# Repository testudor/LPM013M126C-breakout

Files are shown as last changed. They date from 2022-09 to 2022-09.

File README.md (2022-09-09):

# LPM013M126C breakout



This is a breakout board for the LPM013M126C MIP display from JDI. It makes it easy to use with various dev boards like Arduino, etc.

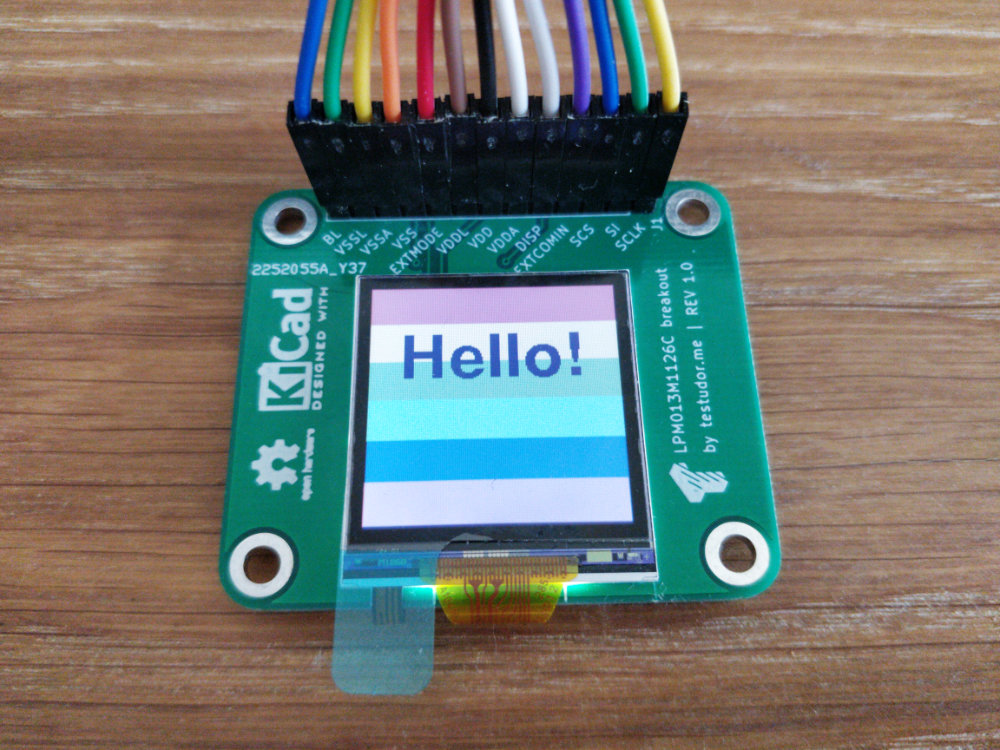
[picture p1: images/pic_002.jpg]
LPM013M126C breakout photo


## Wiring

> **Note** Logic levels as well as supply voltages are 3.3 V. If your use case requires 5 V you'll have to use a level shifter and change the current limiting resistors for the backlight LEDs.

> **Note** Yes, this board has many pins. The display offers the possibility to use separate analog/logic power supplies and I decided to keep this functionality. Same goes for the backlight. For most use cases it's possible to use a common supply for everything.

| PIN | Description | Connect to |
| --- | --- | --- |
| SCLK | Serial Clock Signal | Connect to MCU SPI Clock |
| SI | Serial Data Input Signal | Connect to MCU SPI MOSI |
| SCS | Chip Select Signal | Connect to MCU SPI Chip Select |
| EXTCOMIN | COM Inversion Polarity Input | Not connected |
| DISP | Display ON/OFF Switching Signal | Connect to any digital pin |
| VDDA | Power Supply for Analog | Connect to +3.3 V |
| VDD | Power Supply for Logic | Connect to +3.3 V |
| VDDL | Power Supply for LED | Connect to +3.3 V |
| EXTMODE  | COM Inversion Mode Select Terminal | Not connected |
| VSS | Logic Ground | Connect to GND |
| VSSA | Analog Ground | Connect to GND |
| VSSL | LED Ground | Connect to GND |
| BL | LED Backlight Input | Connect to any digital pin |

## EXTMODE Jumper

Set EXTMODE to 'L' for use with the library mentioned below

## Software

The display works great with the [JDI_MIP_Display](https://github.com/Gbertaz/JDI_MIP_Display) library! Just make sure to set the right resolution in the config file.

## Further Information

For more information regarding the display please refer to the [official datasheet](https://www.j-display.com/product/pdf/Datasheet/5LPM013M126C_specification_ver03.pdf)!

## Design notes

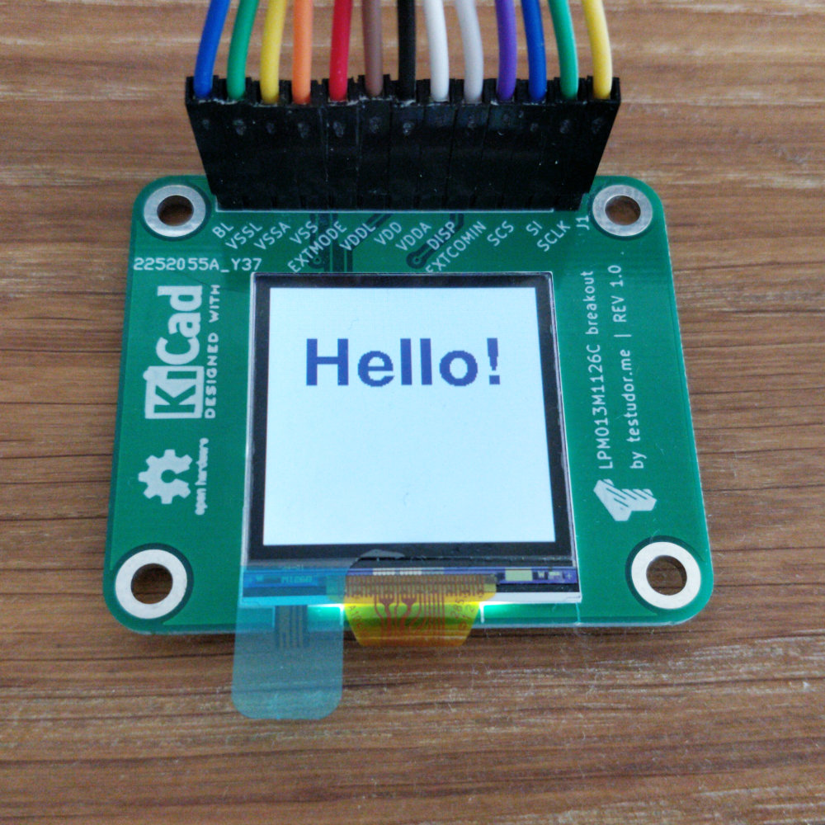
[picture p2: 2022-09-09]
images/pic_001.jpg

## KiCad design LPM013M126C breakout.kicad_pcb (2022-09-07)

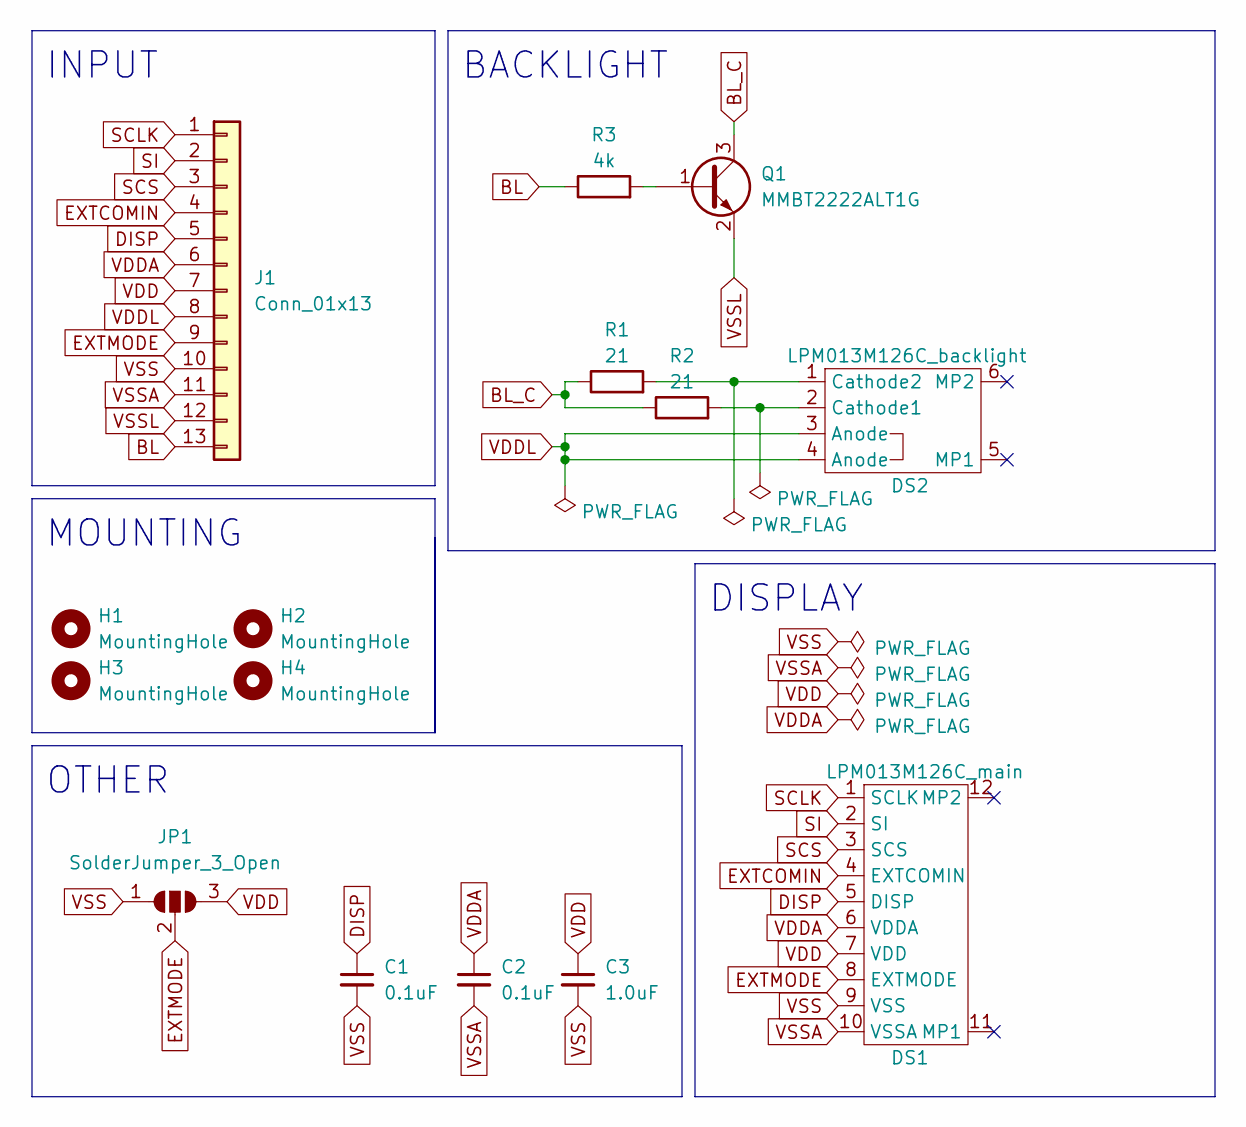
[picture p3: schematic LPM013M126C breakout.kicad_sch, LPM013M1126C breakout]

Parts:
C1, C2: 0.1uF; C_0402_1005Metric
C3: 1.0uF; C_0402_1005Metric
DS1: LPM013M126C_main; 5034801000
DS2: LPM013M126C_backlight; 503480-0400
H1, H2, H3, H4: MountingHole; MountingHole_3.2mm_M3_ISO14580_Pad_TopBottom
J1: Conn_01x13; PinHeader_1x13_P2.54mm_Vertical
JP1: SolderJumper_3_Open; SolderJumper-3_P1.3mm_Open_RoundedPad1.0x1.5mm_NumberLabels
Q1: MMBT2222ALT1G; SOT-23
R1, R2: 21; R_0402_1005Metric
R3: 4k; R_0402_1005Metric

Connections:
BL: J1.13, R3.1
BL_C: Q1.3 (C), R1.1, R2.1
DISP: C1.1, DS1.5 (DISP), J1.5
EXTCOMIN: DS1.4 (EXTCOMIN), J1.4
EXTMODE: DS1.8 (EXTMODE), J1.9, JP1.2 (C)
unnamed: DS2.1 (Cathode2), R1.2
unnamed: DS2.2 (Cathode1), R2.2
unnamed: Q1.1 (B), R3.2
SCLK: DS1.1 (SCLK), J1.1
SCS: DS1.3 (SCS), J1.3
SI: DS1.2 (SI), J1.2
VDD: C3.1, DS1.7 (VDD), J1.7, JP1.3 (B)
VDDA: C2.1, DS1.6 (VDDA), J1.6
VDDL: DS2.3 (Anode), DS2.4 (Anode), J1.8
VSS: C1.2, C3.2, DS1.9 (VSS), J1.10, JP1.1 (A)
VSSA: C2.2, DS1.10 (VSSA), J1.11
VSSL: J1.12, Q1.2 (E)

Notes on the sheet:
DISPLAY
MOUNTING
OTHER
INPUT
BACKLIGHT

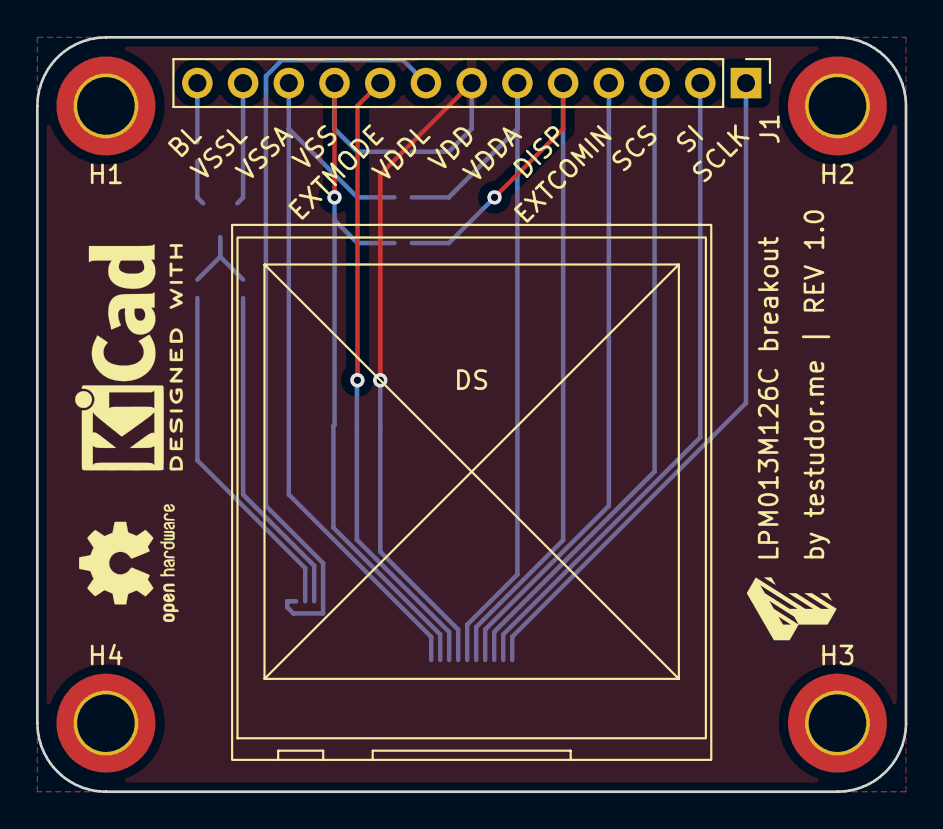
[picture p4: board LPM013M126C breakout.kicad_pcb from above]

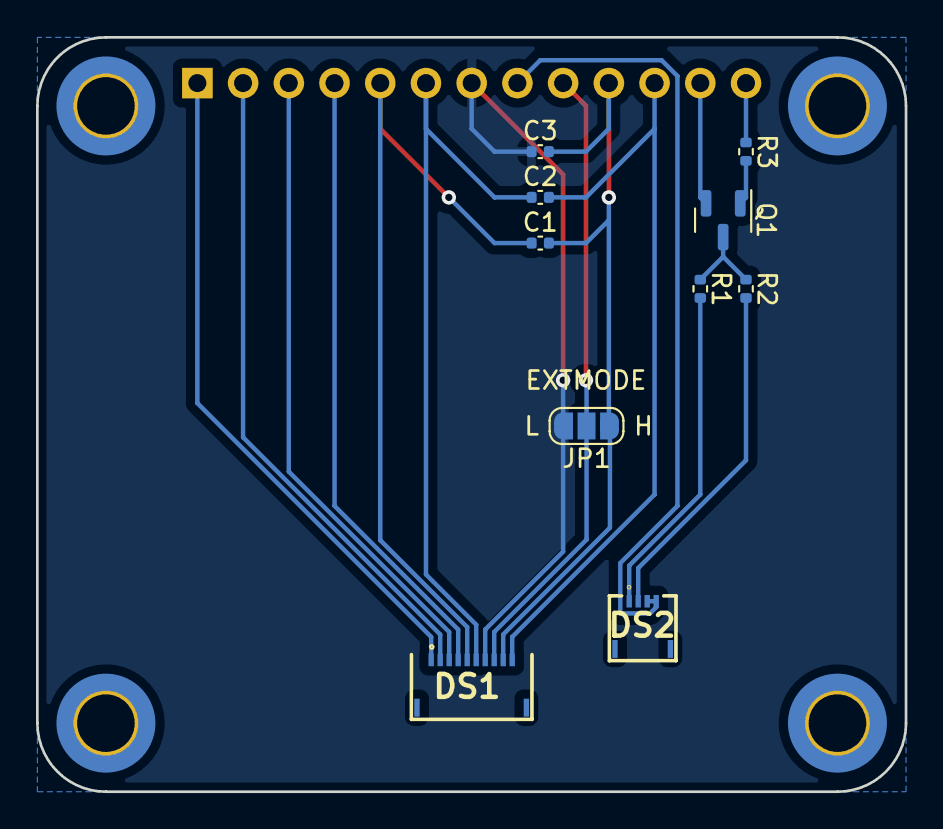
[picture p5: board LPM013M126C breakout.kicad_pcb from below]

Board: 2 copper layers, 48.3 x 41.9 mm, 19 parts (10 on the bottom side), 17 nets.

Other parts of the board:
DS: LPM013M126C; LPM013M126C_silk
LOGO1: KiCad-Logo2_5mm_SilkScreen
LOGO2: OSHW-Logo2_7.3x6mm_SilkScreen
LOGO3: Testudor-Logo_5mm_SilkScreen

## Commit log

2022-08-03 change logo to library version
    [LPM013M126C breakout.kicad_pcb]
2022-08-03 fix references for R1, R2
    [LPM013M126C breakout.kicad_pcb, LPM013M126C breakout.kicad_sch]
2022-08-04 Add BJT for backlight
    [LPM013M126C breakout.kicad_pcb, LPM013M126C breakout.kicad_sch]
2022-08-04 add updated wiring table to readme
2022-08-04 add reference designators to logos
    [LPM013M126C breakout.kicad_pcb]
2022-08-04 fix typo on PCB silkscreen
    [LPM013M126C breakout.kicad_pcb]
2022-09-07 modified pipeline to only run DRC and ERC checks
    [LPM013M126C breakout.kicad_pcb, LPM013M126C breakout.kicad_sch]
